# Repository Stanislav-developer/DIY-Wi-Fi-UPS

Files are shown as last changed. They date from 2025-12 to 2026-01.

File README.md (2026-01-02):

# DIY WiFi-UPS
## Джерело безперебійного живлення для WiFi роутерів та ONU терміналів

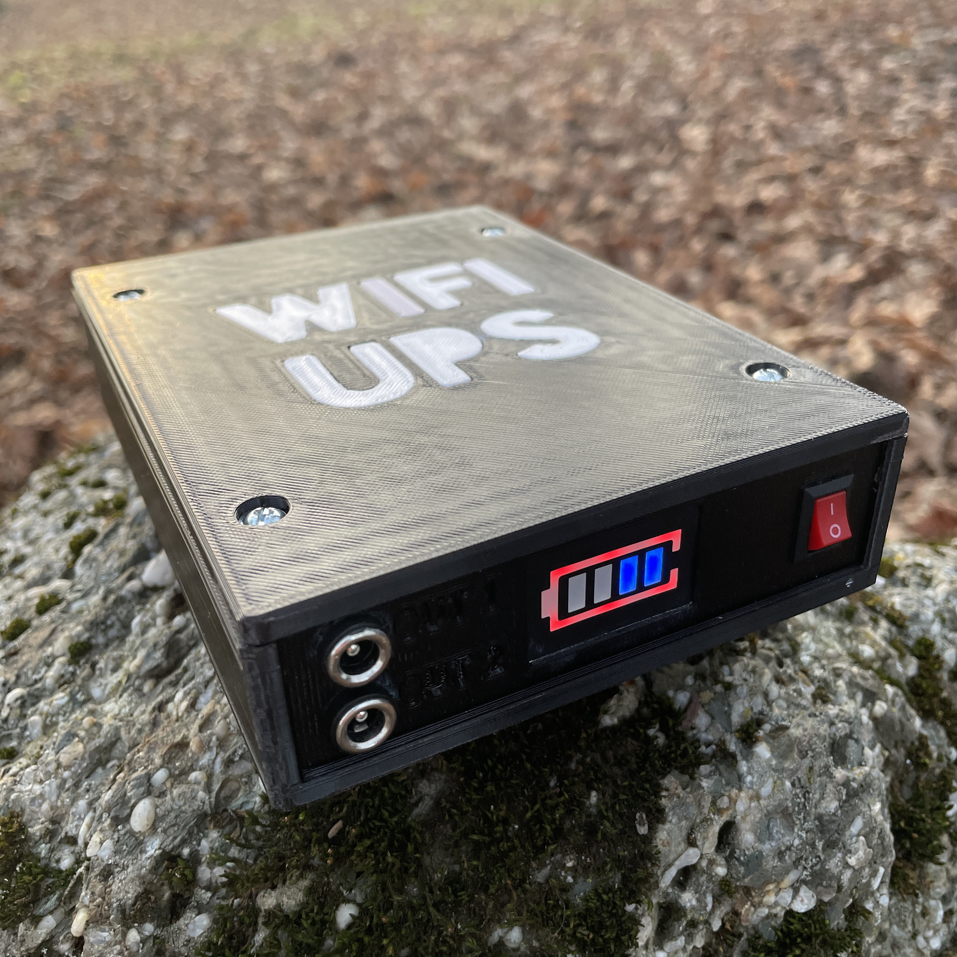
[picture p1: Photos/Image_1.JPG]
Main_Image


## 🎥 Відеоогляд


# Опис:
WiFi-UPS (ДБЖ для роутера) — це пристрій, який забезпечує безперебійне живлення для вашого Wi-Fi роутера та ONU-терміналу. Він складається з доступних компонентів і електронних модулів, що робить його простим для повторення. У цьому репозиторії описано будову та принцип роботи пристрою, наведено список необхідних компонентів і покрокову інструкцію зі збірки.

# Технічна інформація:
Особливістю цього безперебійника є безшовне перемикання на резервне живлення, тобто роутер не буде перезавантажуватися під час відключень електроенергії. Живлення безперебійника можливе як від блока живлення роутера (9–12 В, 600 мА–2 А), так і від стандартного блока живлення смартфона через USB Type-C (5 В, 1–3 А).
Пристрій має 2 входи та 2 виходи.
Характеристики вхідних портів:
• IN1 — розʼєм 5.5×2.1 мм, напруга від 6 до 20 В, струм до 3 А;
• IN2 — розʼєм USB Type-C, напруга 4.5–5.5 В, струм до 3 А.
Характеристики вихідних портів:
• OUT1, OUT2 — розʼєм 5.5×2.1 мм, напруга 9/12 В (за потреби може бути налаштована в діапазоні 5–25 В), струм до 1 А на порт.
Максимальна сумарна вихідна потужність на два порти становить 24 Вт.
Також на передній панелі розташовані індикатор заряду акумулятора та вимикач. Як елементи живлення використовуються 4 Li-Ion акумулятори формату 18650 з ємністю понад 1500 мА·год кожен.

# Характеристики у зручній таблиці:

| КАТЕГОРІЯ | ЗНАЧЕННЯ |
| :---: | :---: |
| Час автономної роботи | до 10 годин|
| Тип акумуляторів | Li-Ion 18650 |
| З'єднання елементів | 1s4p |
| Мін. ємність на комірку| 1500mAh |
| К-сть входів| 2 |
| К-сть виходів| 2 |
| Макс. потужність на 2 виходи| 24W |
| IN1 | 5-20 V (max 3A) |
| IN2 | 5V (max 3A) |
| OUT1 | 5/9/12V (max 1A) |
| OUT2 | 5/9/12V (max 1A) |

# Схема
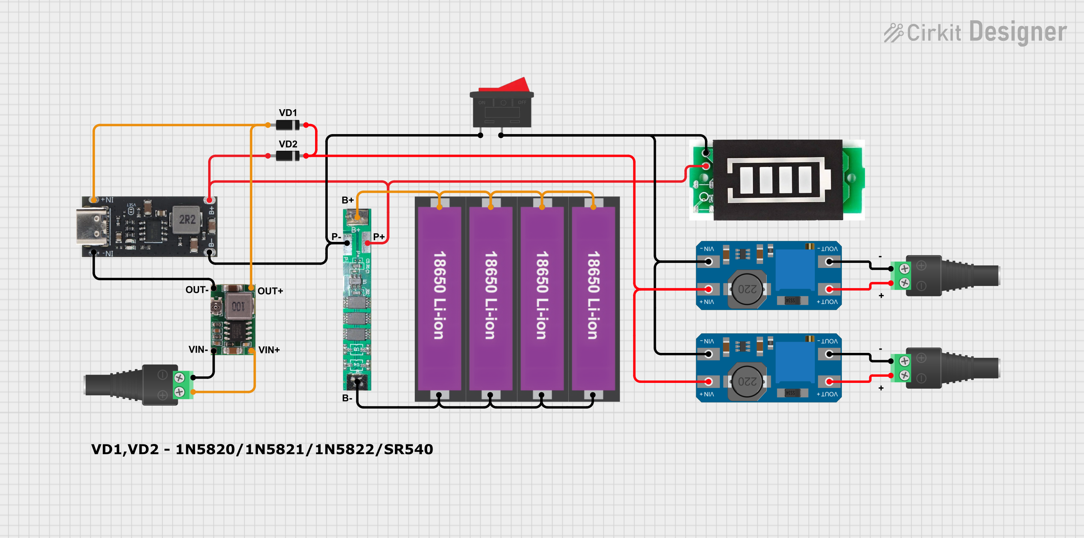
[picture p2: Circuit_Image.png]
Circuit_Image


[Переглянути схему у повній якості](/Circuit_Image.png)

# Принцип роботи
1. Акумулятори під'єднані до плати `BMS 1S 15A`, ця плата виконує функцію захисту від перерозряду та короткого замикання. Чому обрана саме ця бмс? Тому що струм на вході підвищуючих перетворювачів `MT3608` може сягати 6 Ампер і стандартна `BMS 1S` яка розрахована на 3A буде йти в захист.
2. До плати заряду `IP2312` підєднаний понижуючий dc-dc перетворювач `MINI360` призначений для конвертування напруги 9,12 вольт що поступає від блоку живлення роутеру у безпечні 5 вольт для плати заряду.
3. Функцію перемикання живлення від акумуляторів або від мережі виконують 2 діоди шотткі `SR540`. VD1 пропускає напругу 5 вольт якщо присутня мережа, оскільки на цьому діоді більший потенціал то VD2 закритий і напруга з акумуляторів не поступає до підвищуючих перетворювачів та плата заряду безпечно їх заряджає. Якщо електроенергія у мережі зникає, потенціал на VD1 дорівнює 0 і VD2 відкривається та живлення на перетворювачі поступає від акумуляторів. Таким чином виходить система: Присутня мережа - живимо роутер та термінал від мережі та паралельно заряджаємо акумулятори. Мережа зникла - моментально перемикаємося на живлення від акумуляторів(роутер не перезавантажується).
4. Коли ми вмикаємо вимикач, струм паралельно поступає на 2 dc-dc підвищуючі модулі `MT3608` та на `індикатор заряду` акумулятора. Таким чином ми вмикаємо безперебійник.
   
# Корпус

Корпус моделювався у програмі `Fusion360`, у папці [3D models](/3D%20Models/) розміщений файл проекту [f3z](/3D%20Models/V1.1%20(Latest)/Fusion%20file) та [STL](/3D%20Models/V1.1%20(Latest)/STLs) файли для друку. Файли рекомендовано використовувати з папки [V1.1(Latest)](/3D%20Models/V1.1%20(Latest)/) оскільки це остання версія де виправлені деякі дрібні недоліки.

---

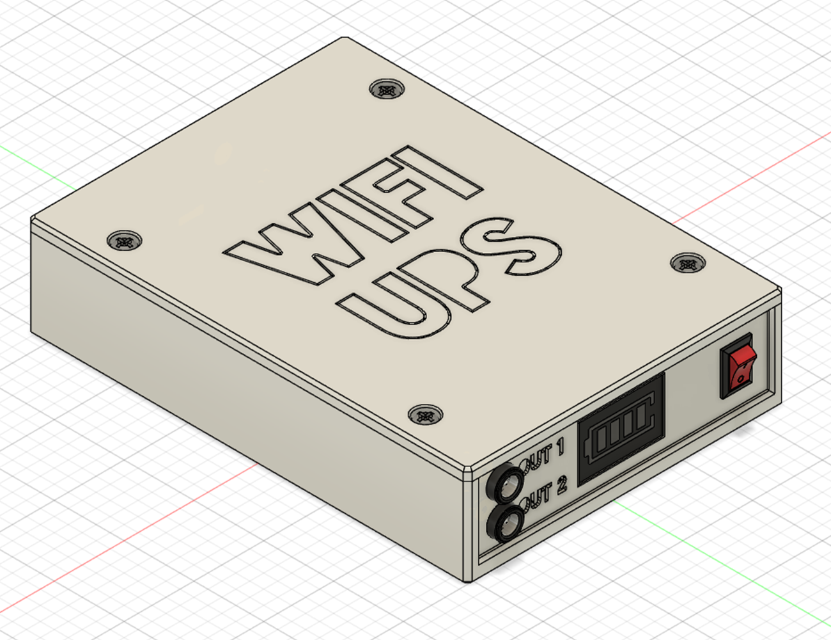
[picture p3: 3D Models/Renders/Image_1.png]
Circuit_Image

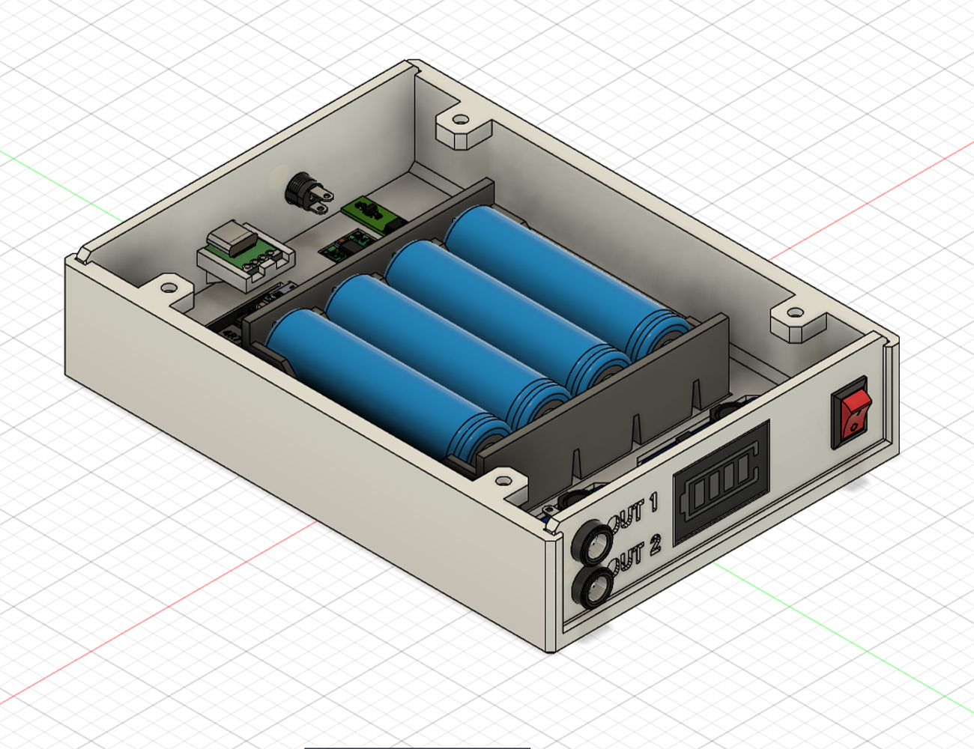
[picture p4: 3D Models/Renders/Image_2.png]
Circuit_Image

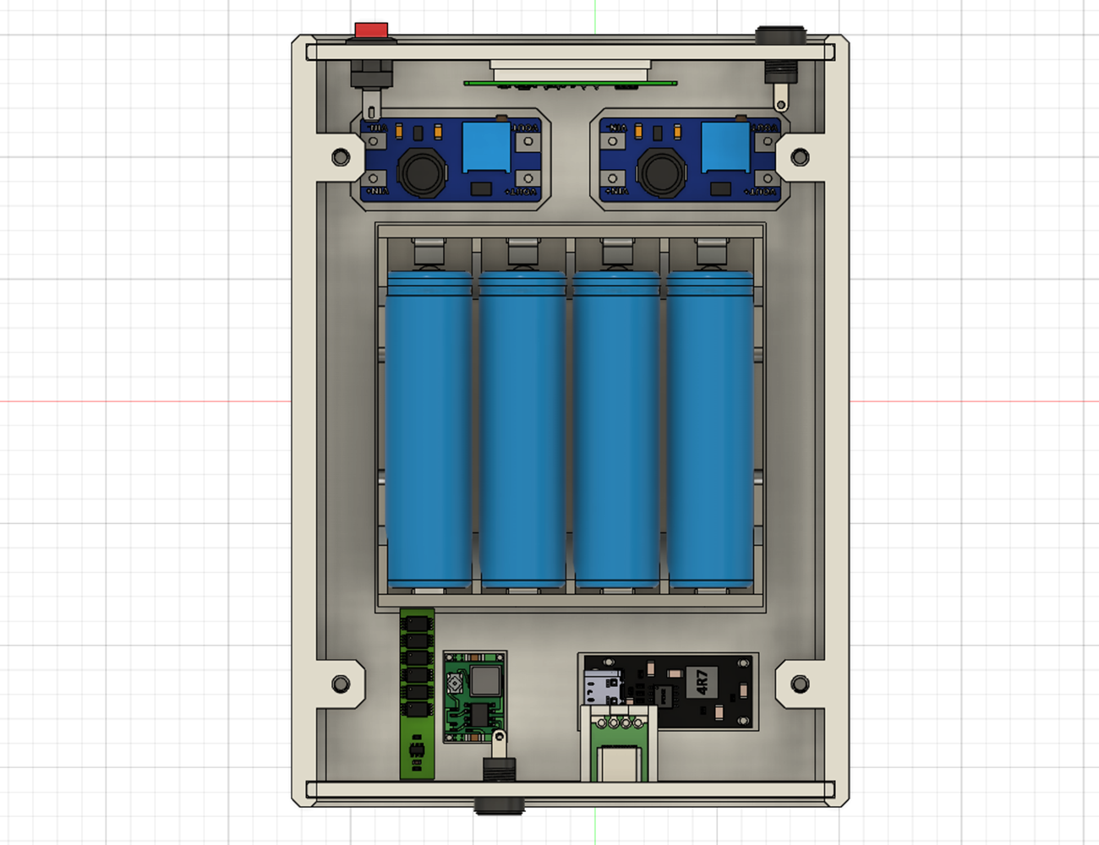
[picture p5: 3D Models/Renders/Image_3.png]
Circuit_Image

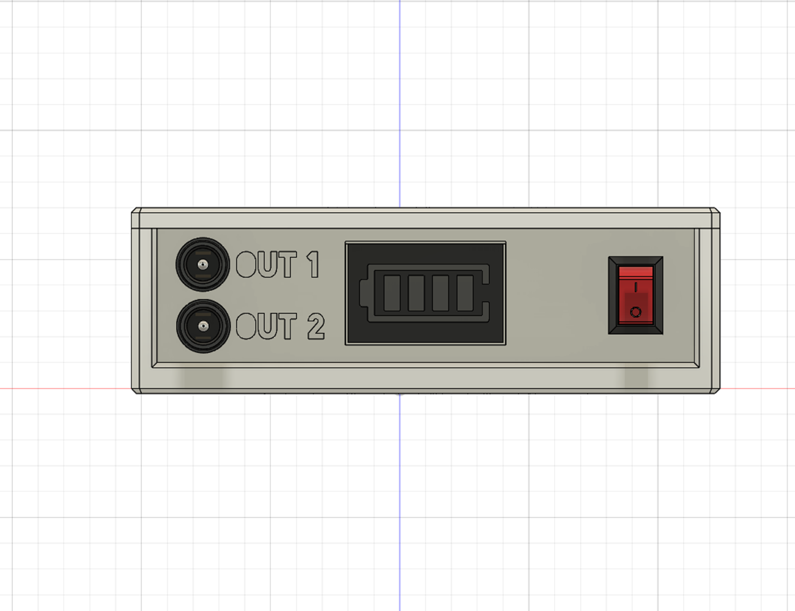
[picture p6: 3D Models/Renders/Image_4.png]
Circuit_Image

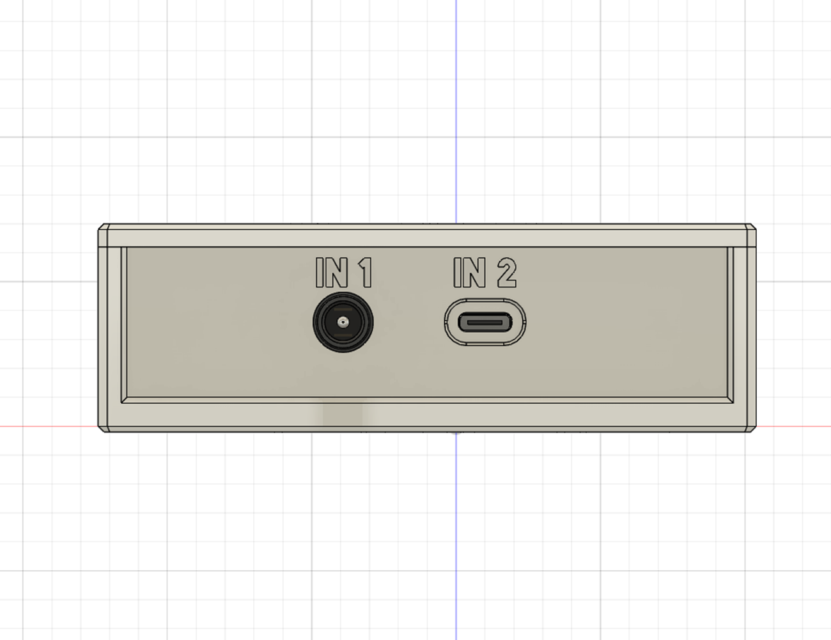
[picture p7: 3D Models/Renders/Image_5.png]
Circuit_Image

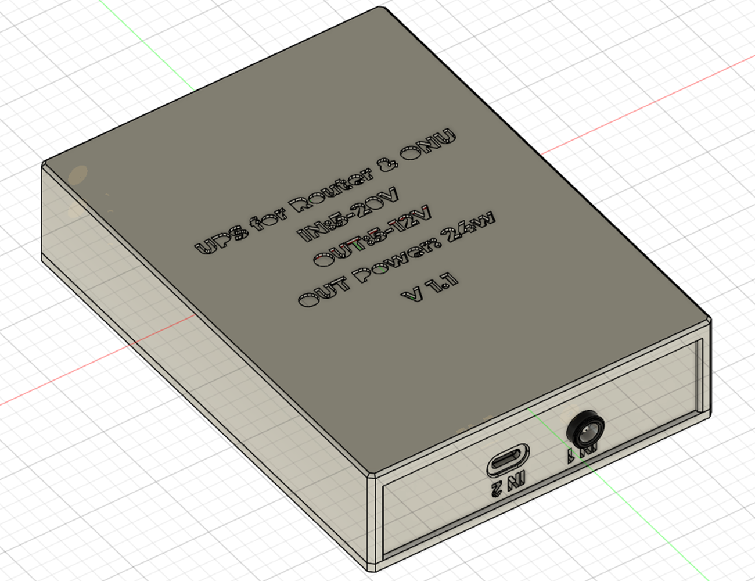
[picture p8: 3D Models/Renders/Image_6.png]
Circuit_Image

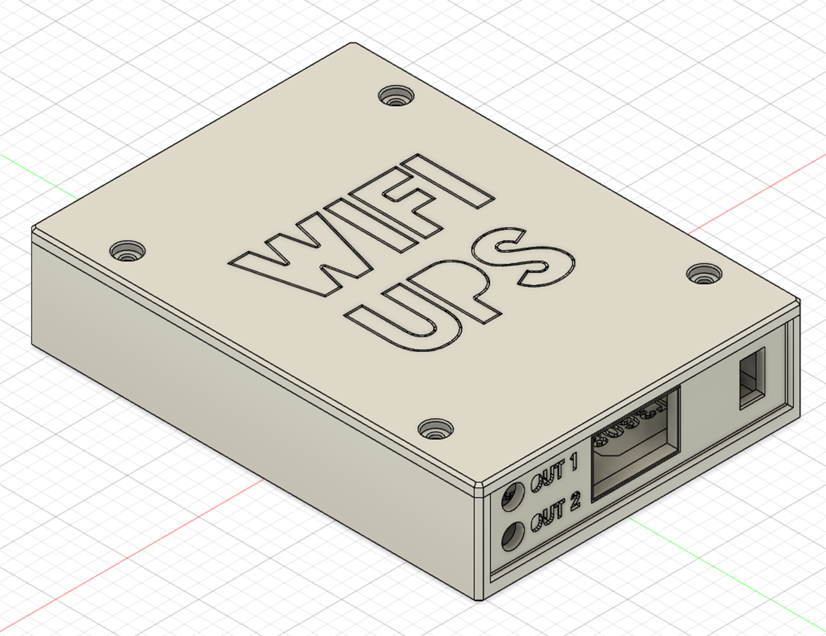
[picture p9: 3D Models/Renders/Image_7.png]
Circuit_Image

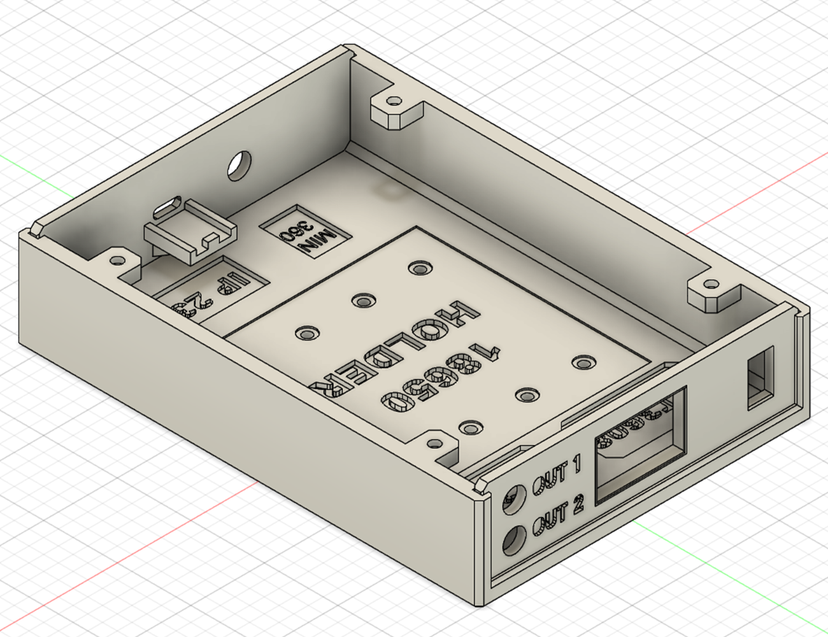
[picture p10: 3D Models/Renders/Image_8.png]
Circuit_Image


Корпус проектувався модульно та складається з 5 частин:
1. Основний кейс
2. Передня панель
3. Задня панель
4. Кришка
5. Букви

Складання корпусу:
У основному кейсі є 4 отвори під гайки М3 та спеціальні пази з двох сторін у які вставляється передня та задня панелі, верхня кришка їх прижимає і закручується болтами M3x6 до основного кейсу, на верхню кришку ми наносимо суперклей у отвори під букви та закладаємо їх.

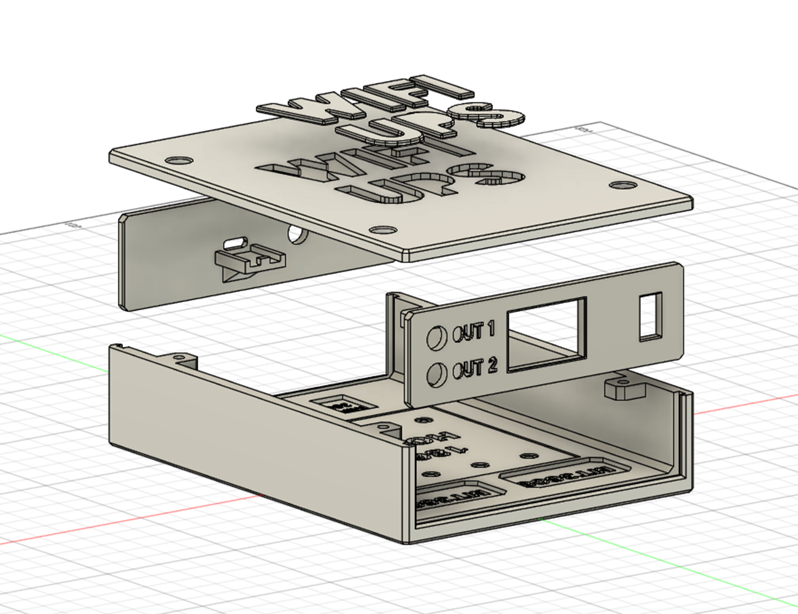
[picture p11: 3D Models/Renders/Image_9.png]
Circuit_Image

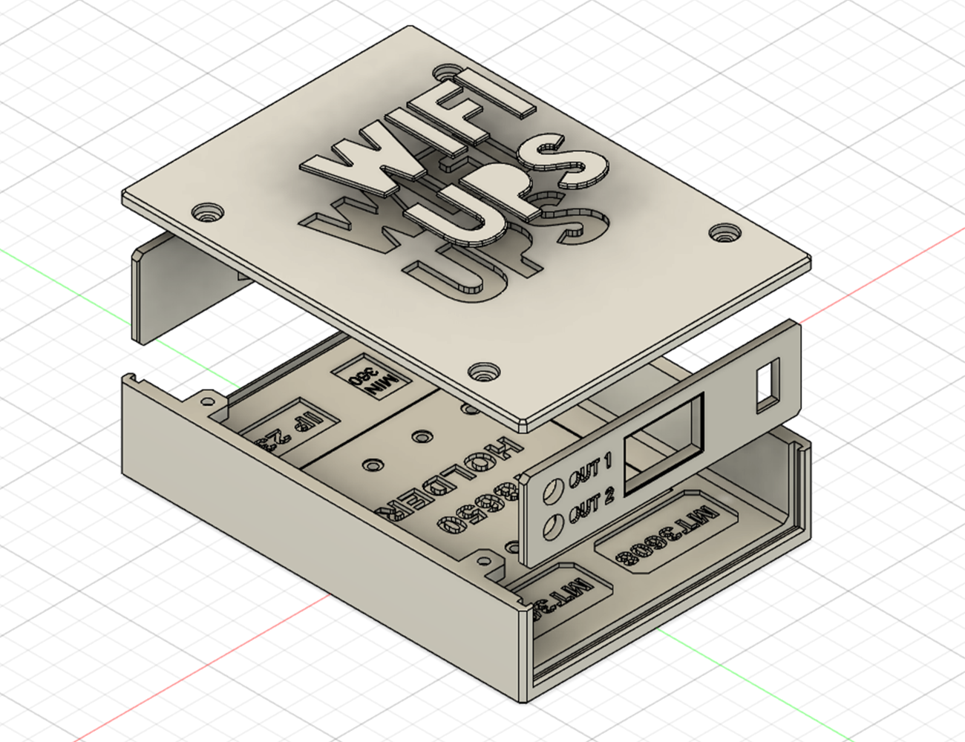
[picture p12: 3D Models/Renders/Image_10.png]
Circuit_Image


## [Файл Fusion f3z для редагування](/3D%20Models/V1.1%20(Latest)/Fusion%20file)
## [STL файли для друку](/3D%20Models/V1.1%20(Latest)/STLs)

# Необхідні компоненти для збірки

| НОМЕР | НАЗВА | КІЛЬКІСТЬ |
| :---: | :---: | :--: |
| 1 | [Холдер для 4-х акумуляторів 18650](https://www.rcscomponents.kiev.ua/product/korpus-dlia-4x18650-gt-18650-pc8_179556.html) | 1шт |
| 2 | [Підвищуючий dc-dc перетворювач MT3608](https://www.rcscomponents.kiev.ua/product/rehulovanyi-dc-dc-step-up-modul-zhyvlennia-mt3608_123033.html) | 2шт |
| 3 | [Плата заряду IP2312](https://www.rcscomponents.kiev.ua/product/modul-zariadnyi-type-c-dlia-18650-1s-3a-4-2v_188209.html) | 1шт |
| 4 | [Понижувальний dc-dc модуль MINI360](https://www.rcscomponents.kiev.ua/product/dc-dc-ponyzhuiuchyi-peretvoriuvach-z-rehuliuvanniam-mini-360-vkhid-4-75v-23v-vykhid-1-0v-17v-2a_200045.html) | 1шт |
| 5 | [Плата BMS 1S 15A](https://myproject.com.ua/bms-6mos-modul-zakhystu-dlia-li-ion-akumuliatora-1s.html) | 1шт |
| 6 | [Індикатор заряду для 1s Li-Ion](https://www.rcscomponents.kiev.ua/product/indykator-zariadu-litiievoi-batarei-1s-synii_211004.html) | 1шт |
| 7 | [DC гніздо 5.5x2.1mm](https://www.rcscomponents.kiev.ua/product/hnizdo-zhyvlennia-chorne-na-korpus-5-5x2-1mm-dc-022b_213085.html) | 3шт |
| 8 | [DC штекер 5.5x2.1mm](https://www.rcscomponents.kiev.ua/product/shteker-na-kabel-2-1-5-5-korotkyi-pc-2-1-5-5-vylka-zhyvlennia-dc-mama-z-korpusom-2-1-5-5-mm-dovzhyna-9mm_25189.html) | 4шт |
| 9 | [Вимикач KCD-11](https://www.rcscomponents.kiev.ua/product/kcd-11-on-off-spst-2p-vymykaie-0-vmykaie-peremykach-klavishnyi-rocker-global-tone_211814.html) | 1шт |
| 10 | [TypeC плата адаптер](https://myproject.com.ua/usb31-type-c-plata-perekhidnyk.html) | 1шт |
| 11 | [Діоди Шотткі 1N5820/SR540](https://www.rcscomponents.kiev.ua/product/sr540_20328.html) | 2шт |
| 12 | [Макетна плата (необов'язково)](https://www.rcscomponents.kiev.ua/product/maketna-plata-2x8-dvostoronnia-zelena_144385.html) | 1шт |
| 13 | [Силіконовий термостійкий кабель 20AWG](https://www.rcscomponents.kiev.ua/product/sylikonovyi-provid-20awg-0-5mm-100-0-08ts-korychnevyi_210526.html) | 3м |
| 14 | [Болти M3x6](https://www.rcscomponents.kiev.ua/product/hvynt-iz-sferychnoiu-holovkoiu-m3x6-nerzhaviiucha-stal-304-ph-din-7985_194111.html) | 12шт |
| 15 | [Гайки М3](https://www.rcscomponents.kiev.ua/product/haika-m3-otsynk-bila-din934-b3-bn117_26436.html) | 4шт |
| 16 | Акумулятори 18650 ємністю > 1500mAh | 4шт |
| 17 | Роздрукований корпус | 1шт |

# Всі деталі в зборі

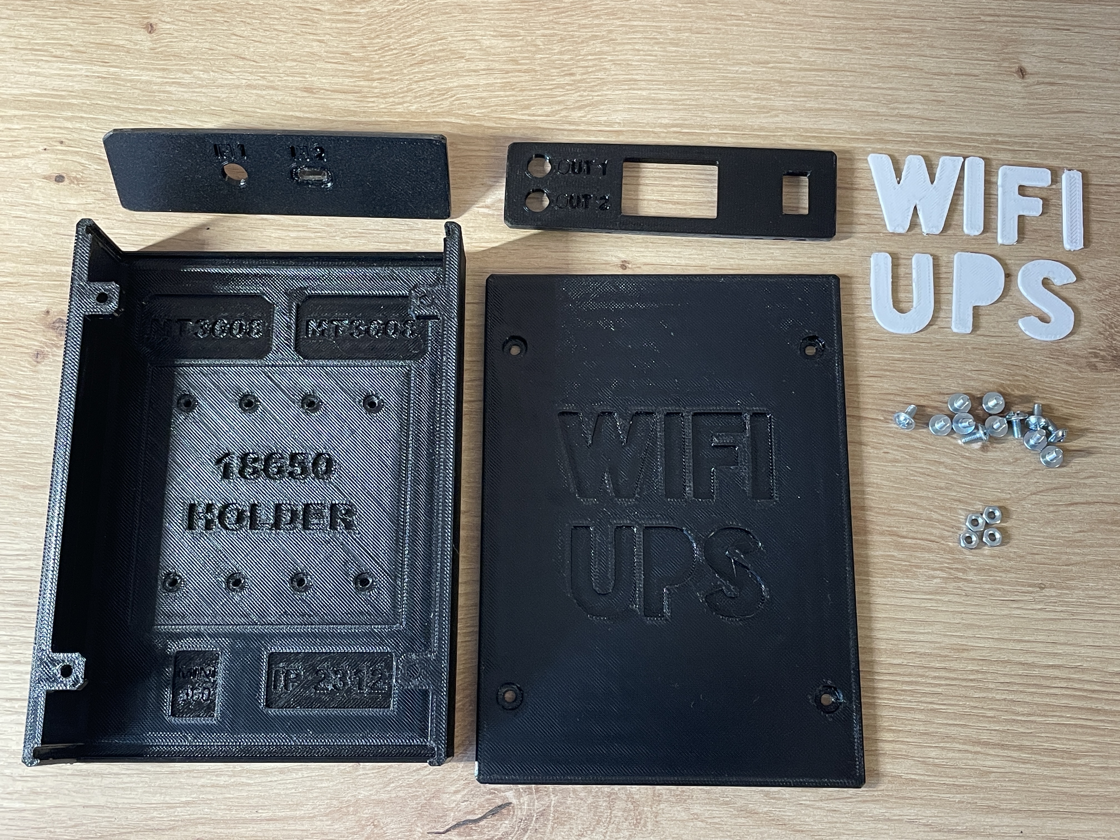
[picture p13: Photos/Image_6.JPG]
Circuit_Image

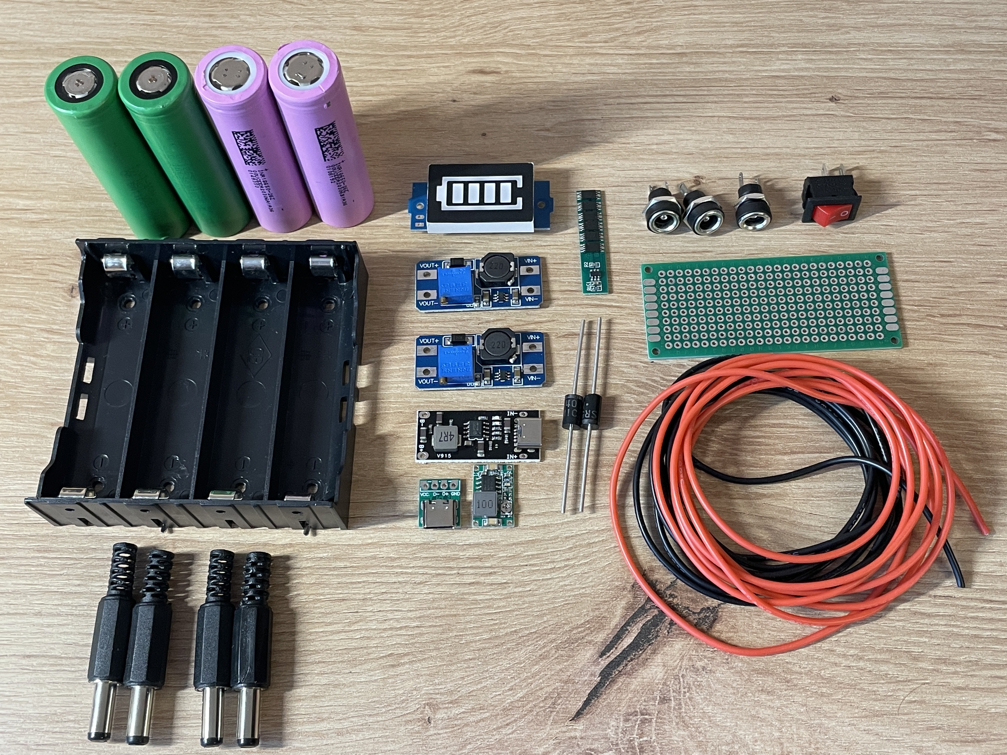
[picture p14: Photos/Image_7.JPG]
Circuit_Image


# Процес збірки
### 1. Припаюємо всі комірки холдера паралельно.
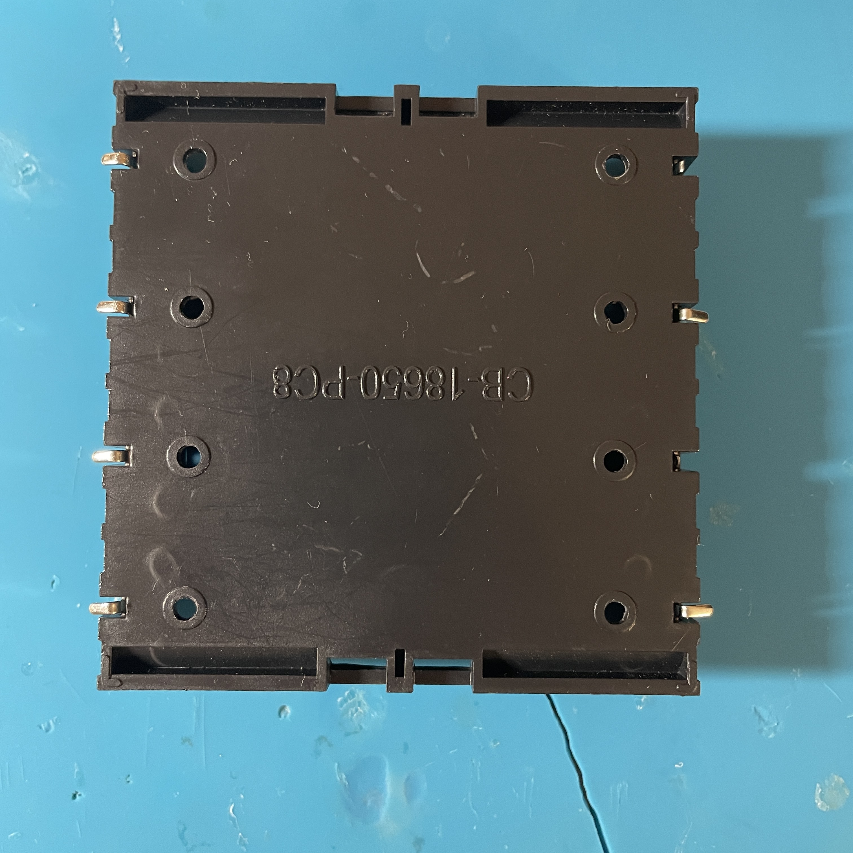
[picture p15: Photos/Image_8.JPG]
Circuit_Image

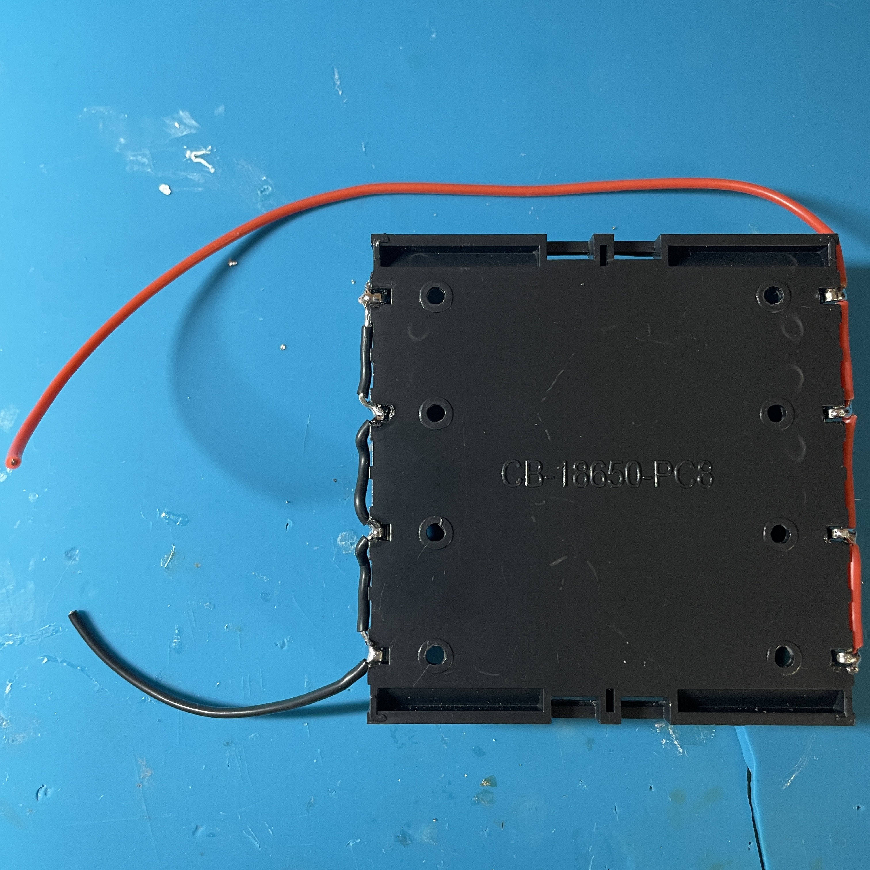
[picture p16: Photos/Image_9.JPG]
Circuit_Image


### 2. Припаюємо плату `BMS 3S 15A`.
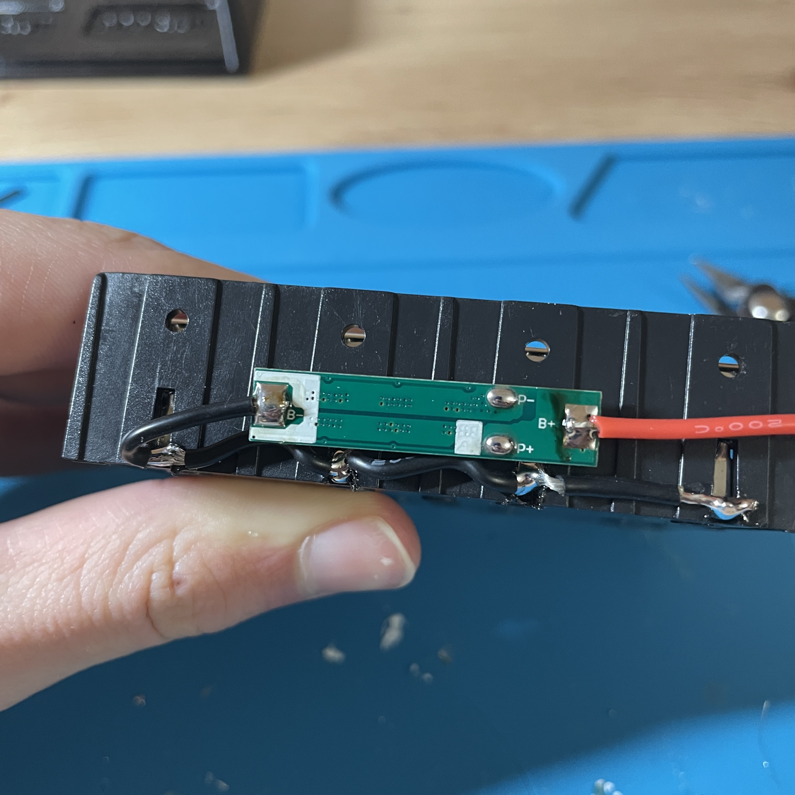
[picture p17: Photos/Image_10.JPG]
Circuit_Image


### 3. Надалі використовуватиметься температурно стійкий клей герметик `Kafuter 704`.
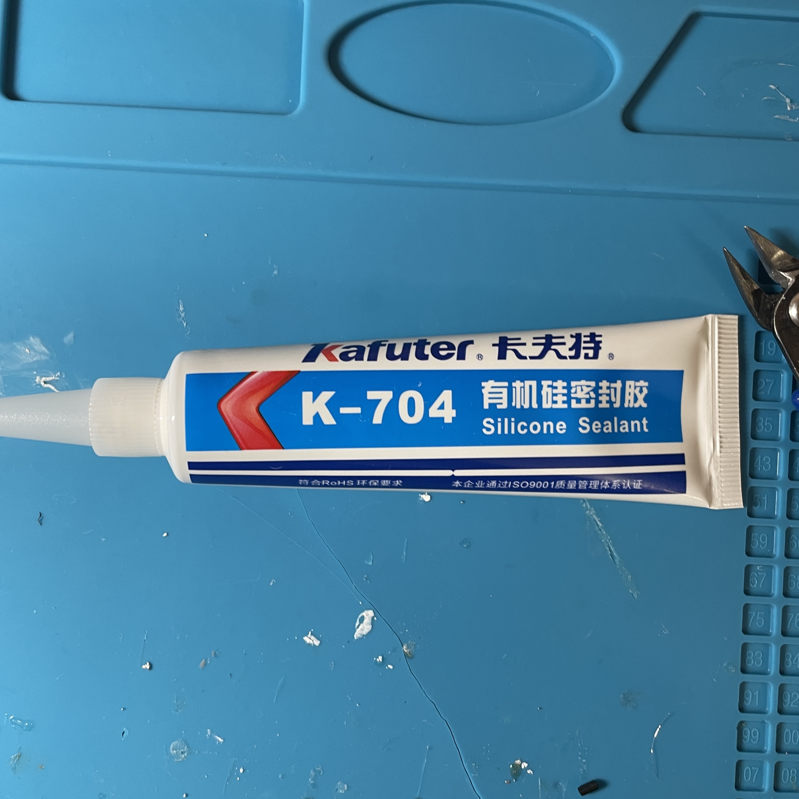
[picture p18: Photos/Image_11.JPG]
Circuit_Image


### 4. Кріпимо плату BMS герметиком на холдер.
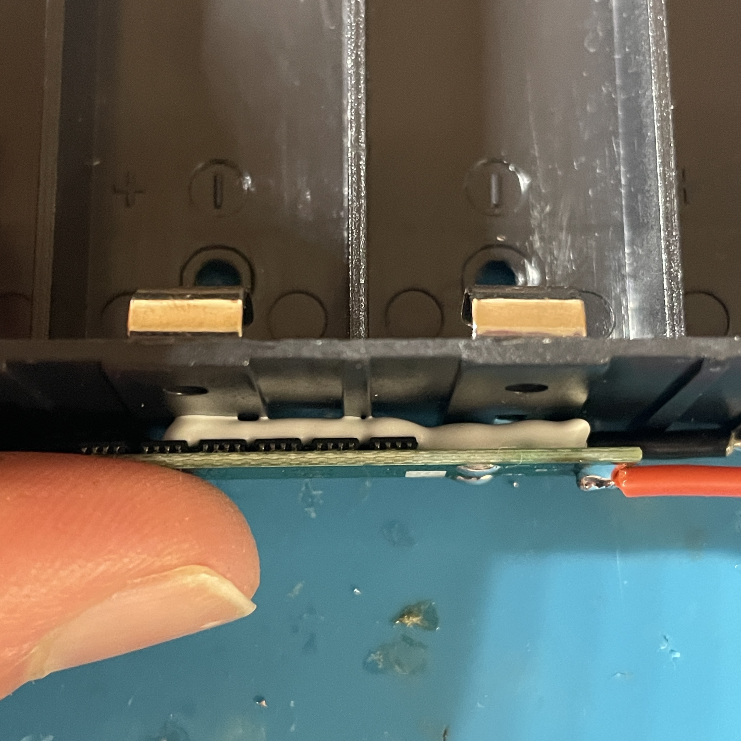
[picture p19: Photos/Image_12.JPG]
Circuit_Image


### 5. Закручуємо холдер болтами у корпус.
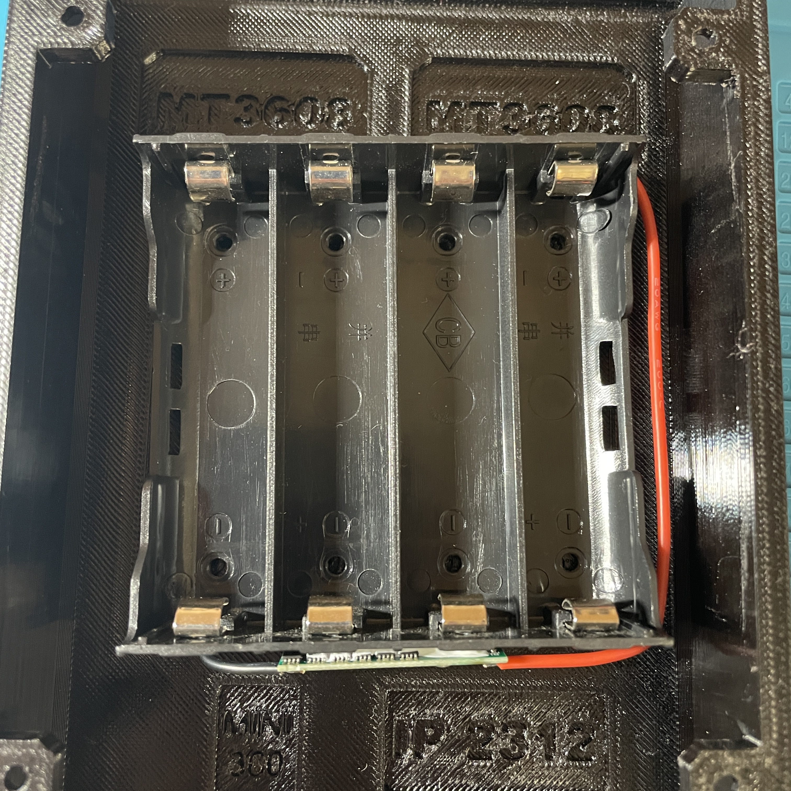
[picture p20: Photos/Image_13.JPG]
Circuit_Image

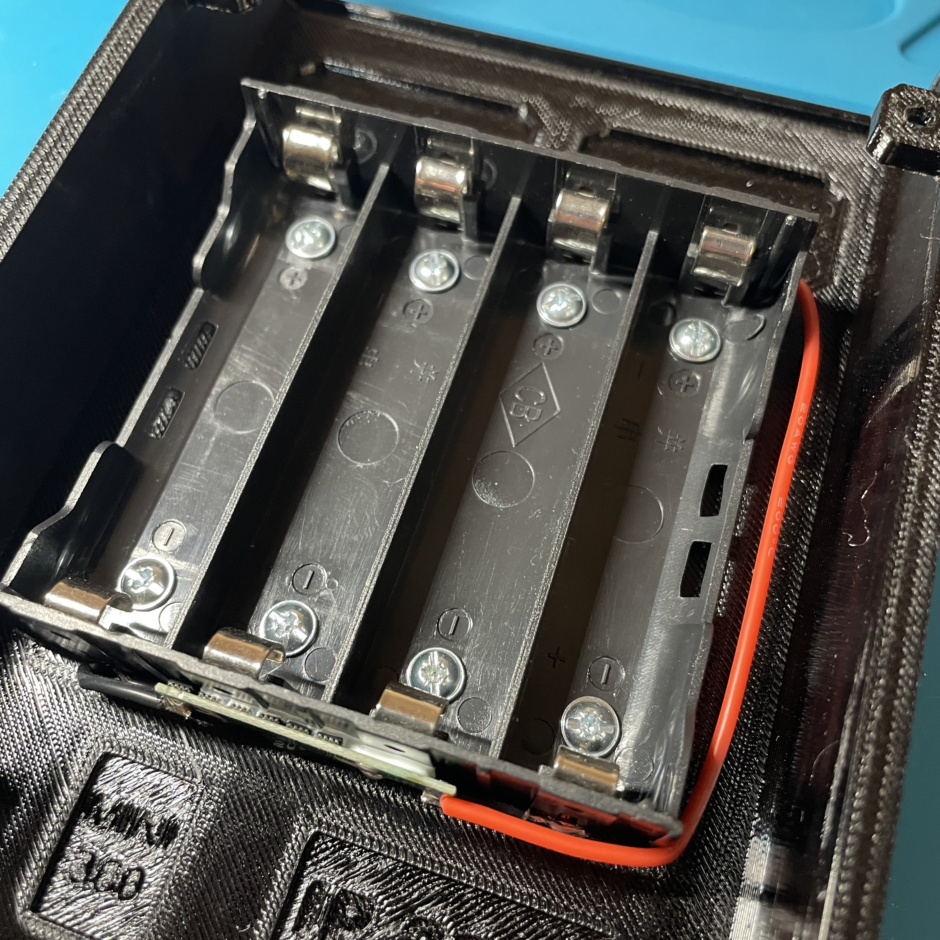
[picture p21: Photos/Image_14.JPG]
Circuit_Image


### 6. Налаштовуємо необхідну напругу на модулях `MT3608` та `MINI360`.
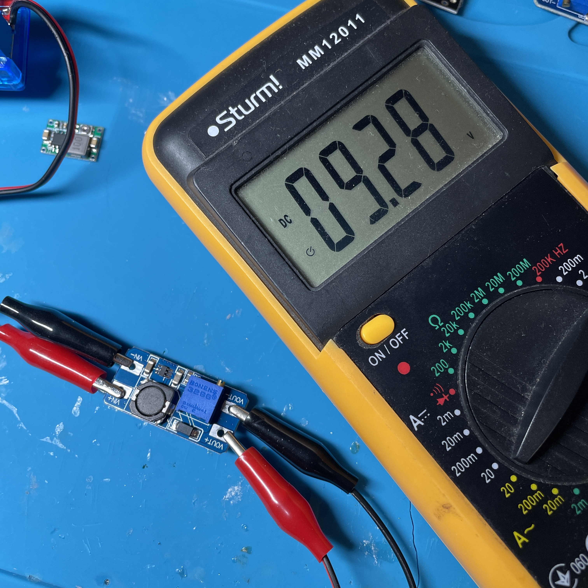
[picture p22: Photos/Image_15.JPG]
Circuit_Image

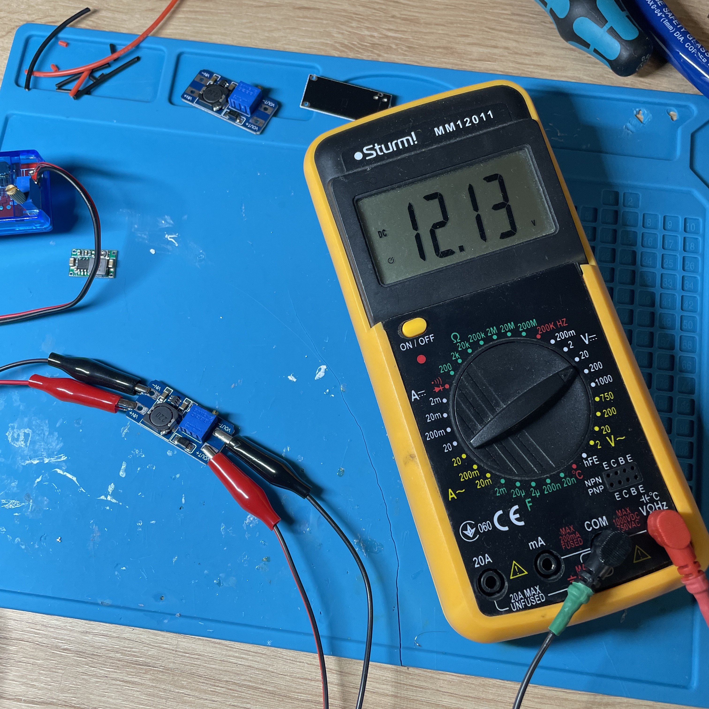
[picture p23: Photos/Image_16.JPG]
Circuit_Image

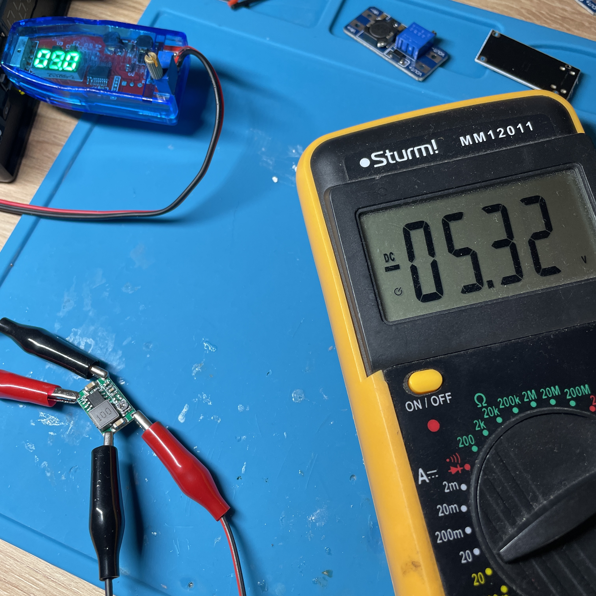
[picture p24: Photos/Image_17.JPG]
Circuit_Image


### 7. Лудимо контакти на модулях.
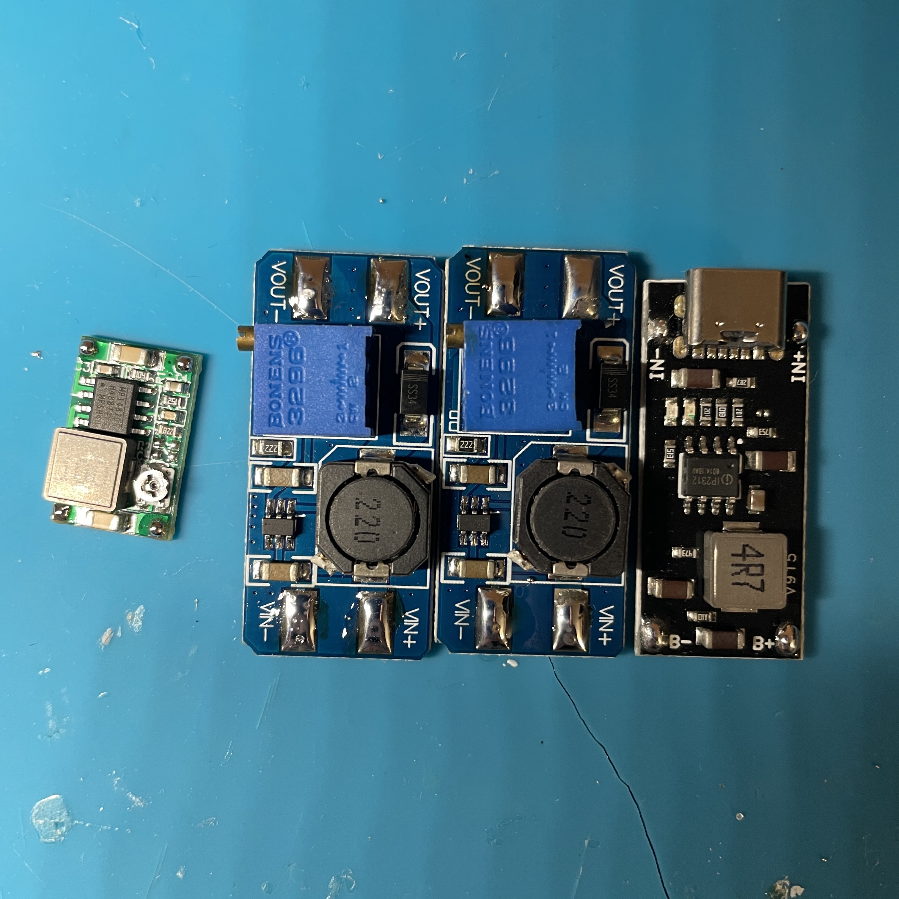
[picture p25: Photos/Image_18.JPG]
Circuit_Image


### 8. Наносимо клей герметик на посадкові місця.
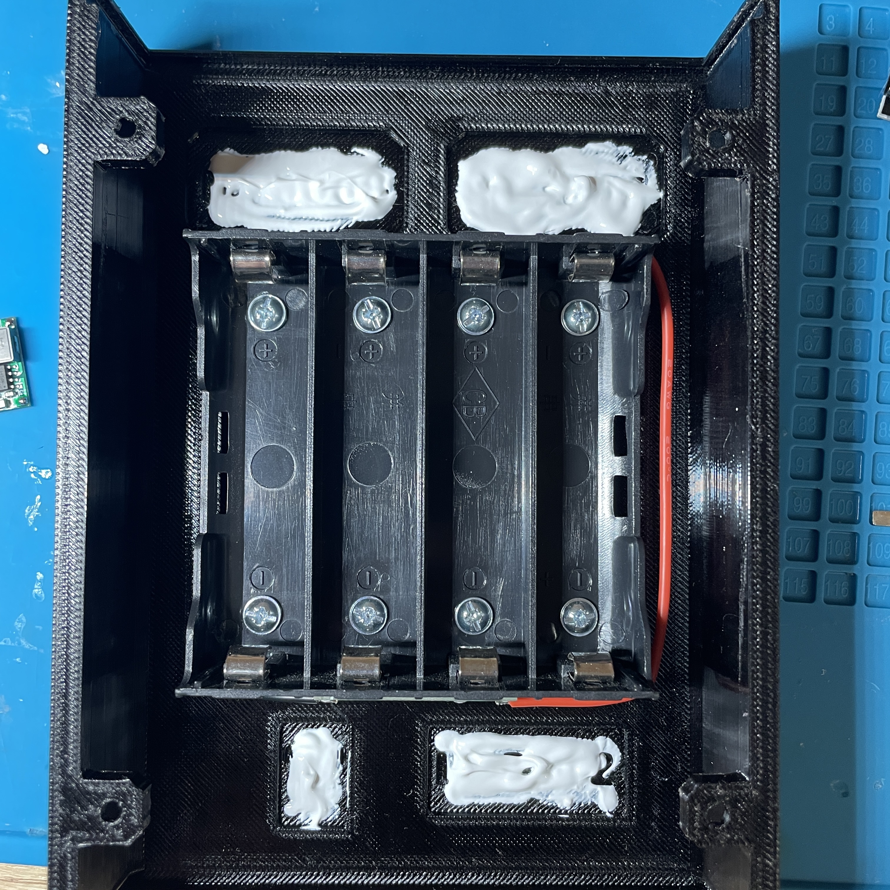
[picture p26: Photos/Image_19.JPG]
Circuit_Image


### 9. Садимо модулі на посадкові місця.
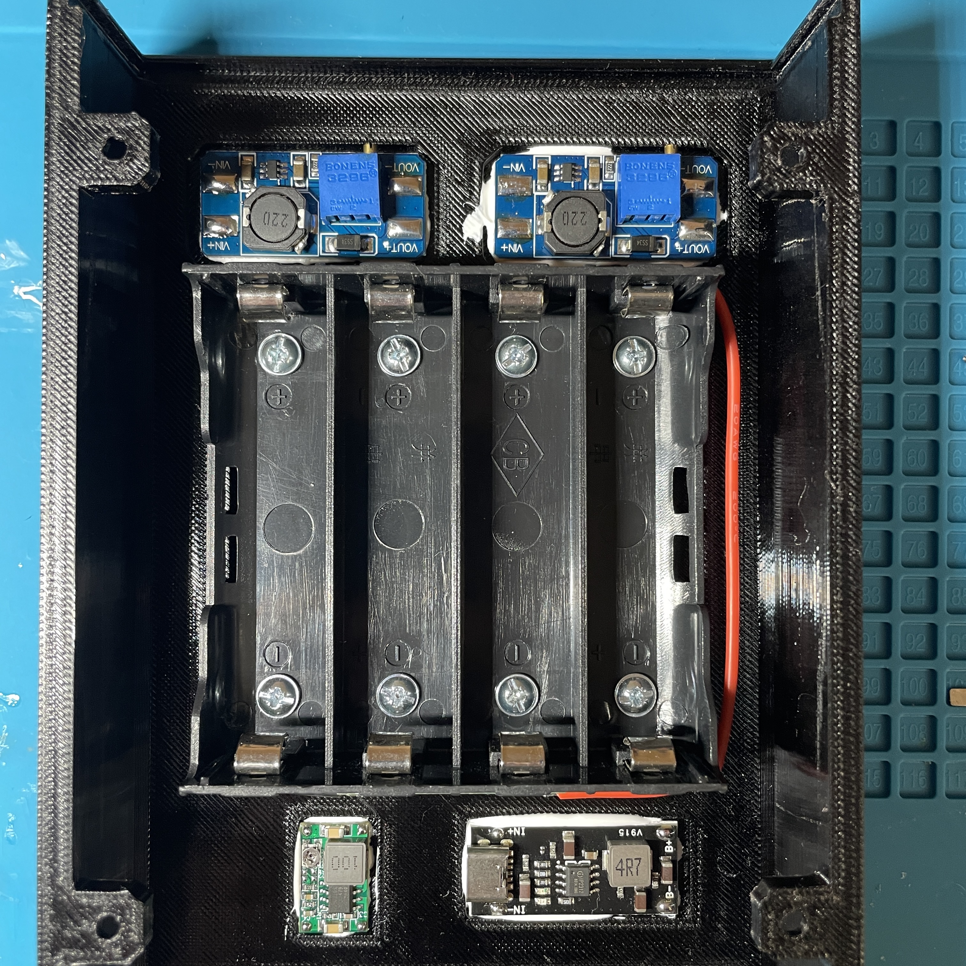
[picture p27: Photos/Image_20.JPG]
Circuit_Image


### 10. Лудимо контакти та вставляємо `плату адаптер з type-c роз'ємом` у паз.
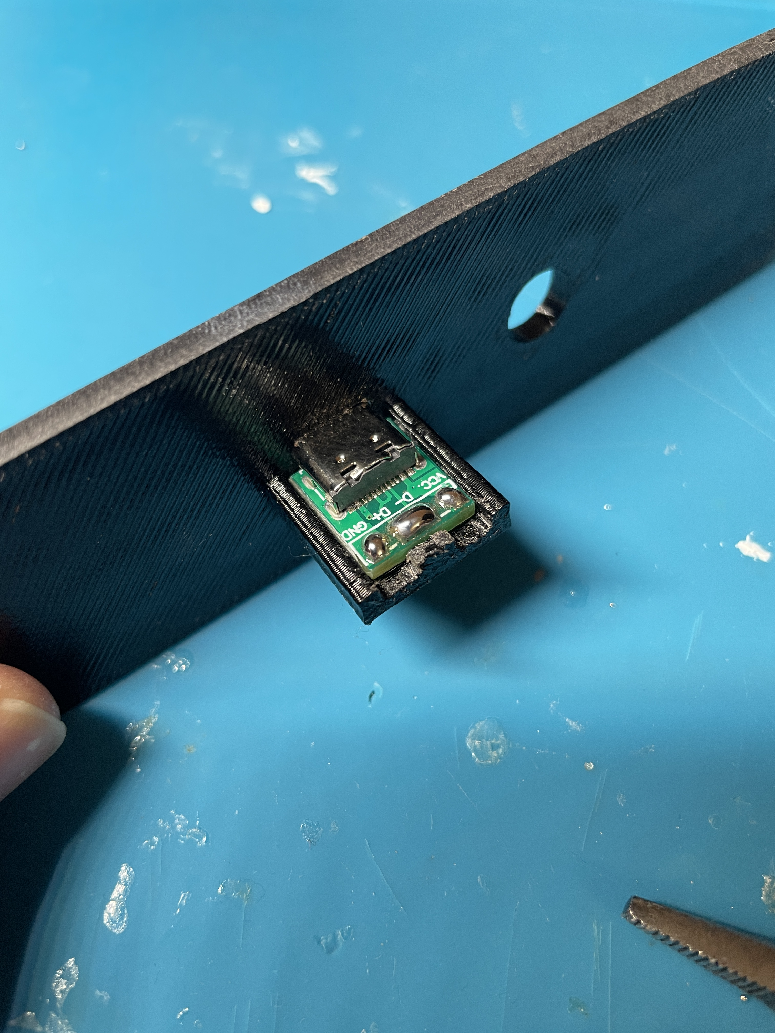
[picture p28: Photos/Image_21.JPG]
Circuit_Image


### 11. Припаюємо кабелі до DC гнізд та ізолюємо термоусадками.
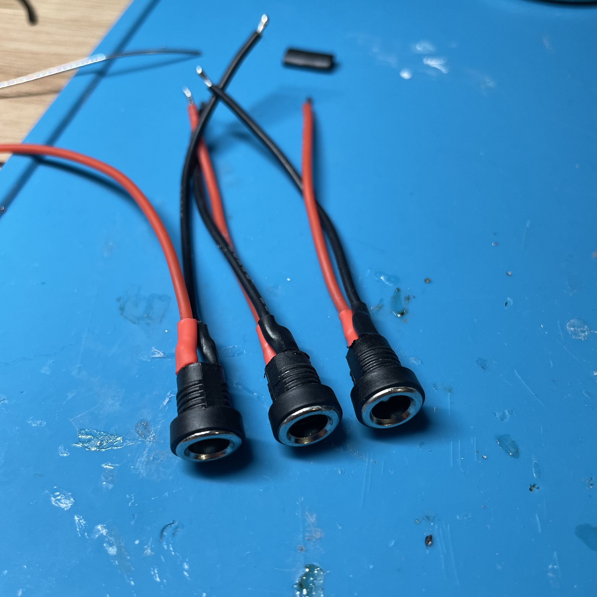
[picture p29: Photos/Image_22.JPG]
Circuit_Image


### 12. Закріплюємо гнізда на передній та задній панелі.
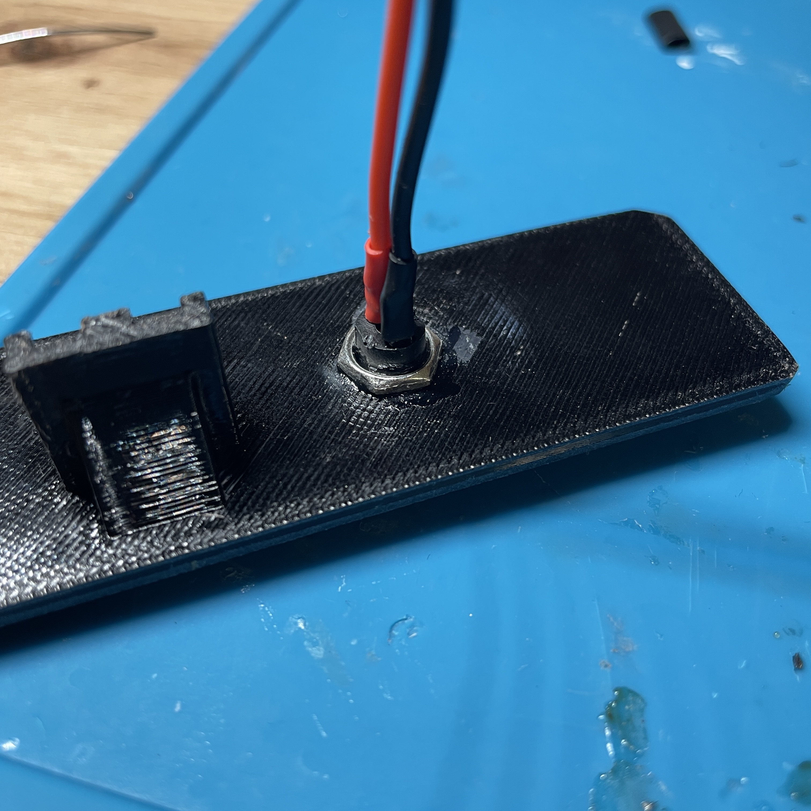
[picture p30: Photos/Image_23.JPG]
Circuit_Image

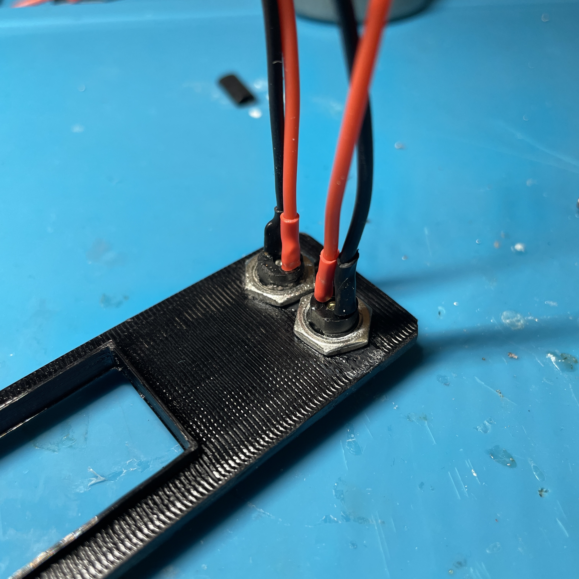
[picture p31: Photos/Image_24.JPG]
Circuit_Image


### 13. Припаюємо кабелі до `індикатора заряду` та вставляємо його у паз на передній панелі.
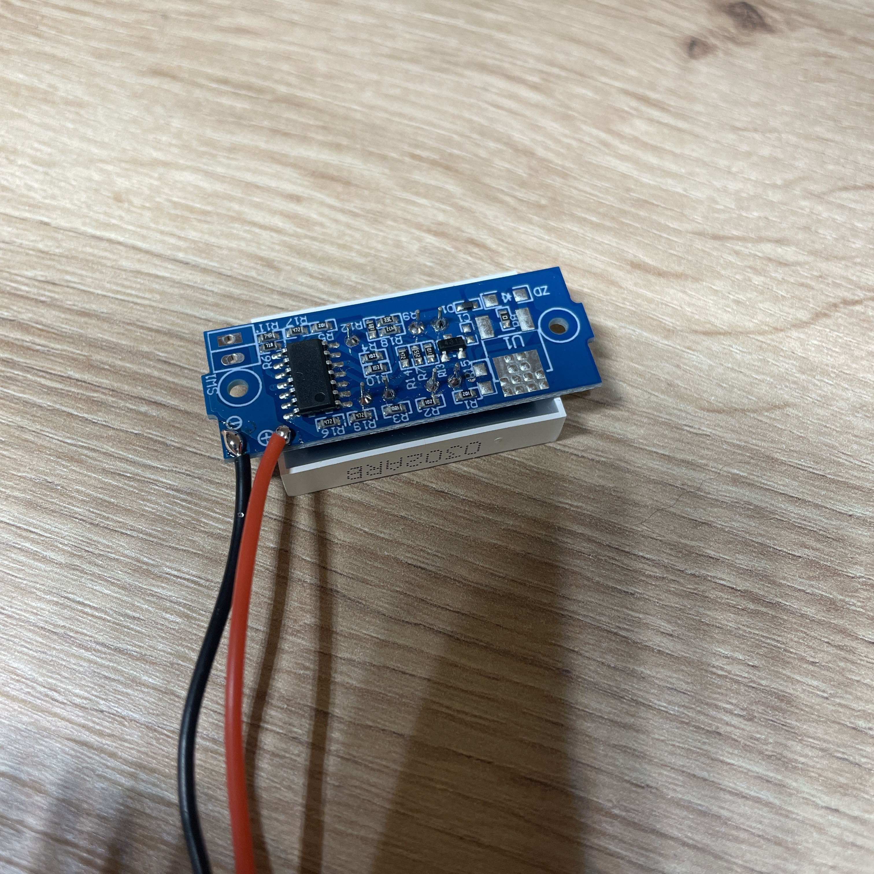
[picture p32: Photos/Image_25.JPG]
Circuit_Image

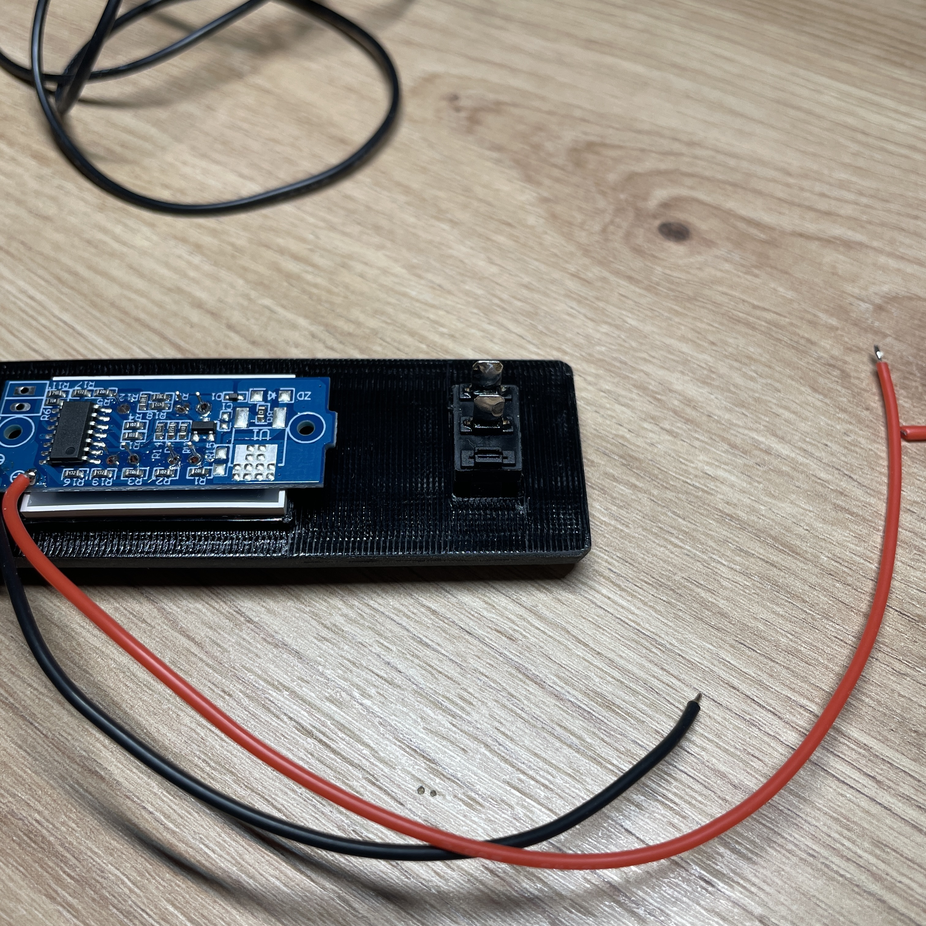
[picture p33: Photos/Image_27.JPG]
Circuit_Image

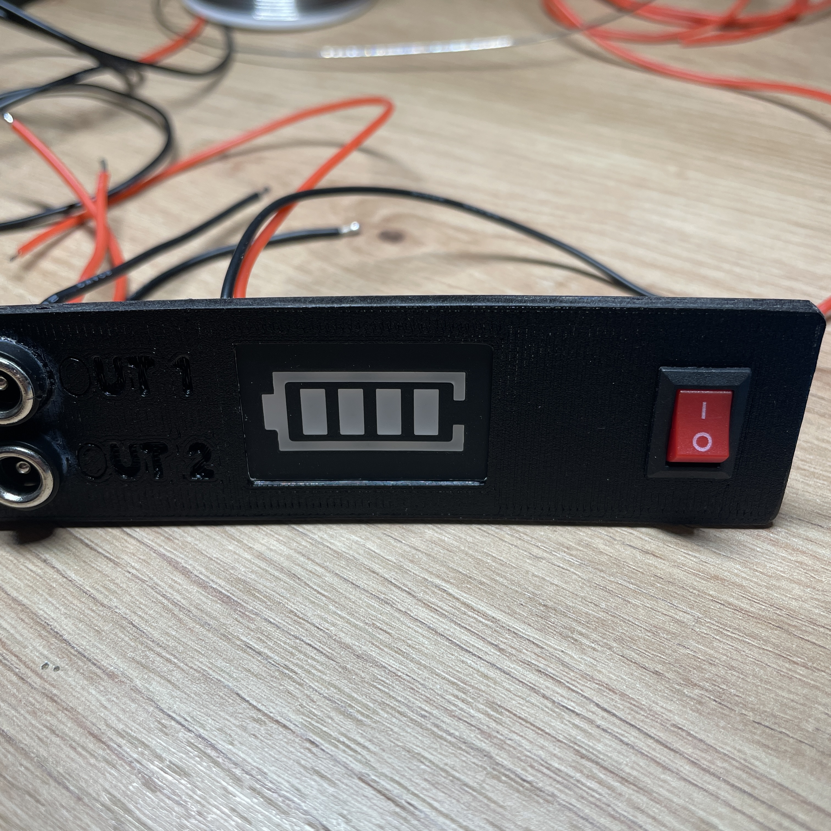
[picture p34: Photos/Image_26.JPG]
Circuit_Image


### 14. Запаюємо 2 діоди на макетну плату.
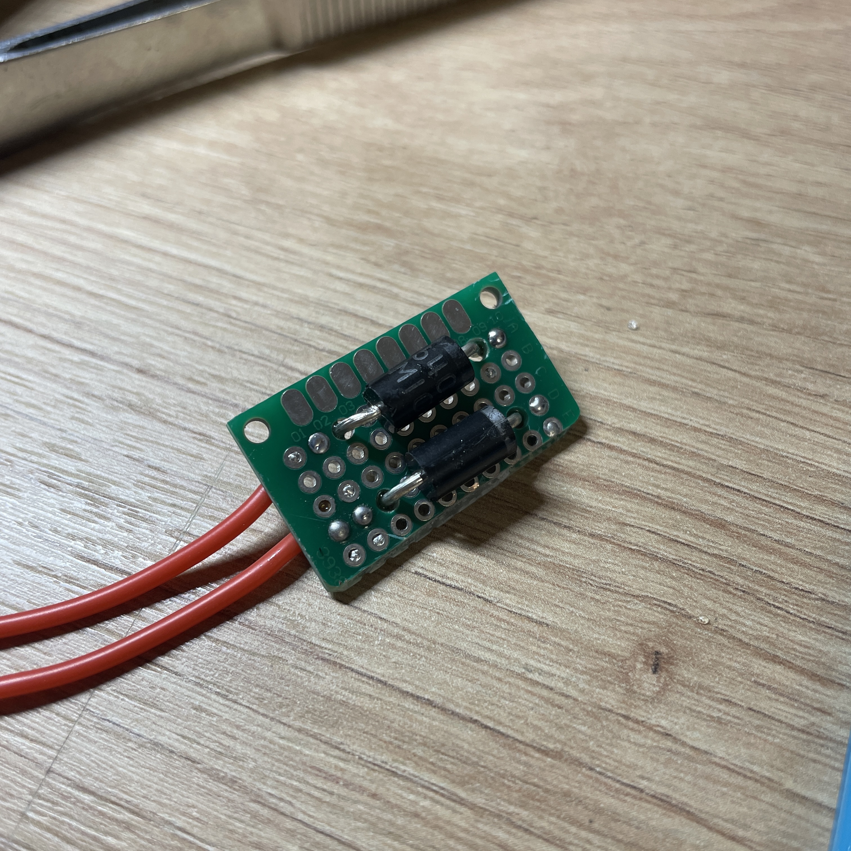
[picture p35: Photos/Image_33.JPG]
Circuit_Image

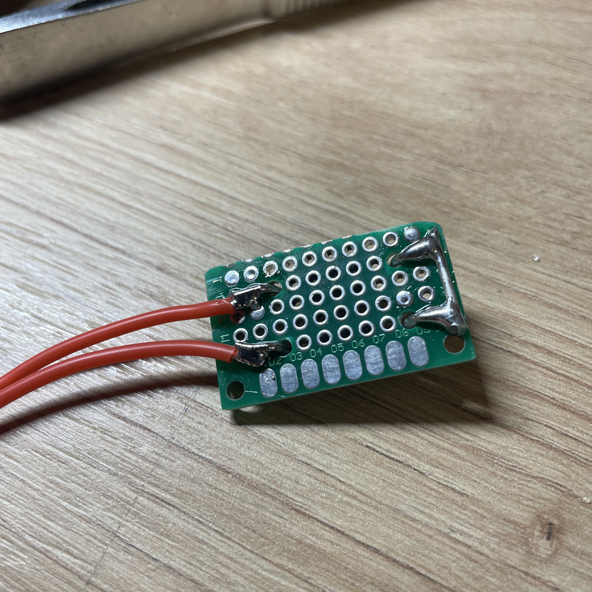
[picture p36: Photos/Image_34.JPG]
Circuit_Image


### 15. Далі паяємо всі провідники по схемі.
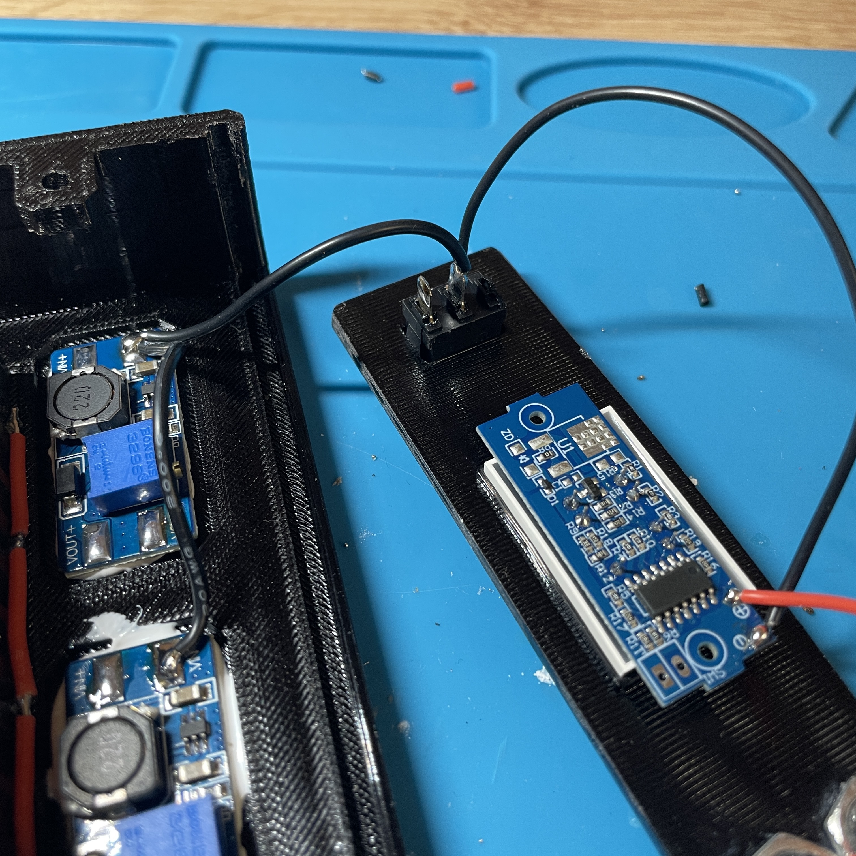
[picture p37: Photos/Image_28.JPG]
Circuit_Image

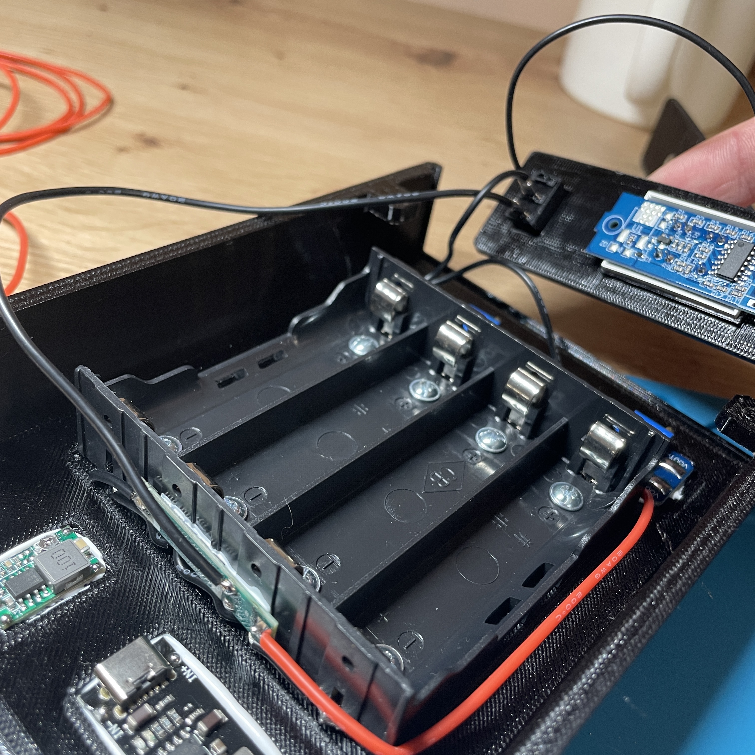
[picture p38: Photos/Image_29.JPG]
Circuit_Image

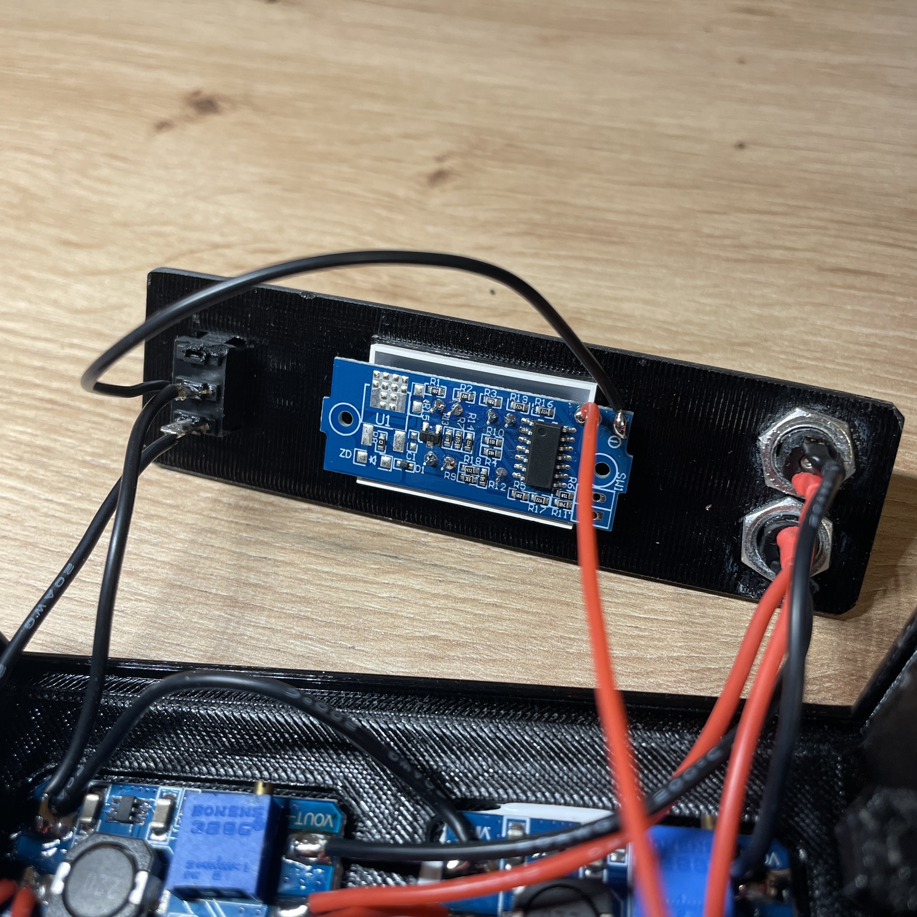
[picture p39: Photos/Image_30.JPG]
Circuit_Image

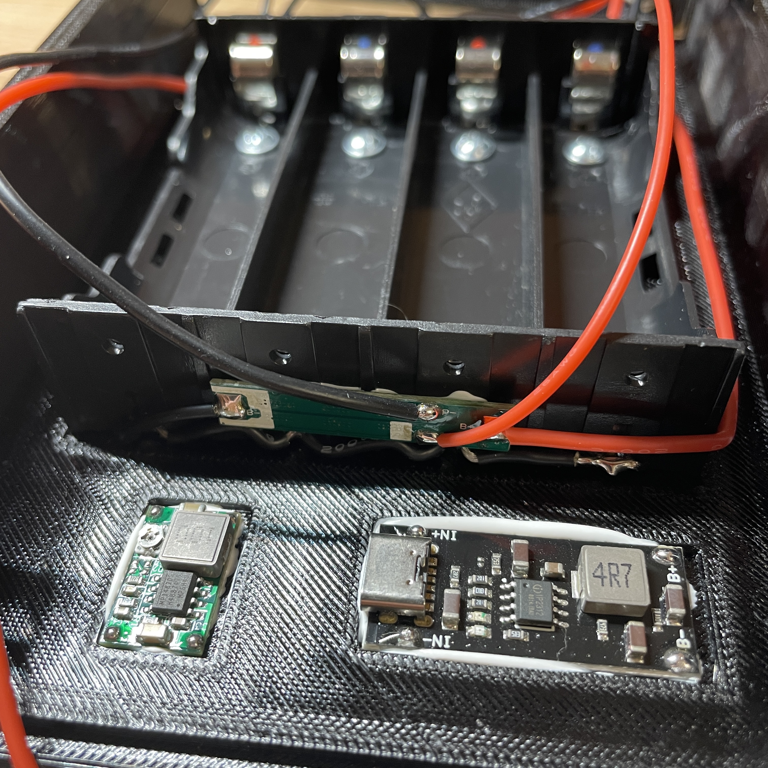
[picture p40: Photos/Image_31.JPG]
Circuit_Image

Circuit_Image
Circuit_Image
Circuit_Image
Circuit_Image

Circuit_Image

### 16. Ще раз перевіряємо схему на правильність підключення та правильною полярністю вставляємо акумулятори у холдер.
Circuit_Image
Circuit_Image

### 17. На верхню кришку по середині клеємо якийсь ущільнювач з паралону чи гуми, щоб акумулятори не випадали з холдеру.
Circuit_Image

### 18. Закладаємо гайки у пази, закладаємо верхню кришку, закручуємо болтами та вклеюємо надруковані букви. 
Circuit_Image

### 19. Далі зробимо 2 DC-DC кабеля для роутера та ONU терміналу
Circuit_Image

### 20. Припаюємо + та - до штекерів
Circuit_Image

### 21. Закручуємо пластикові кожухи.
Circuit_Image

# Фінальний результат:
Circuit_Image
Circuit_Image
Circuit_Image
Circuit_Image
Circuit_Image

# 💬 Зворотний зв'язок

Буду вдячний за підтримку цього проєкту! Відкритий до критики, запитань, порад і пропозицій.

**Зв'яжіться зі мною:**



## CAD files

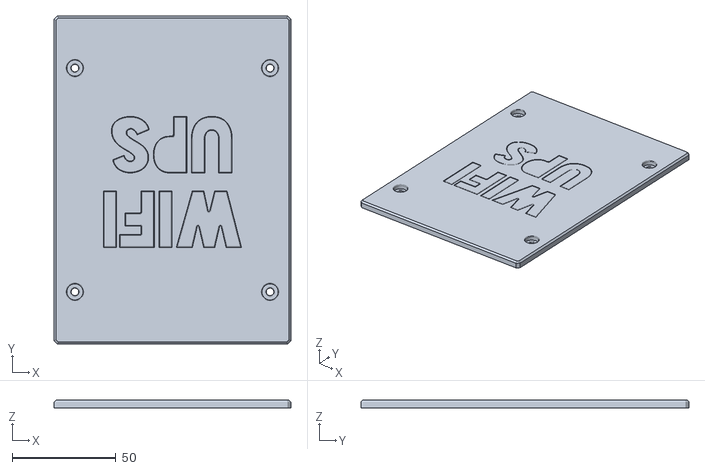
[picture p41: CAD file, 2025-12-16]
3D Models/V1.0/STLs/Cover.stl
114.0 x 158.0 x 4.00

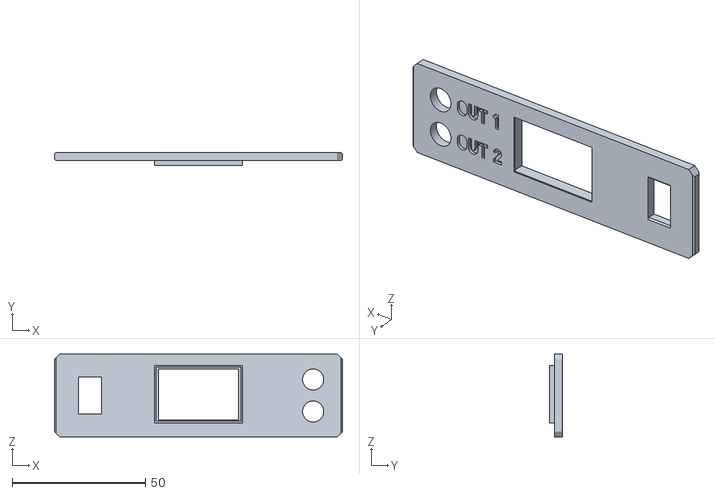
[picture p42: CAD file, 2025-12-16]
3D Models/V1.1 (Latest)/STLs/Front_Panel.stl
108.0 x 5.00 x 31.0

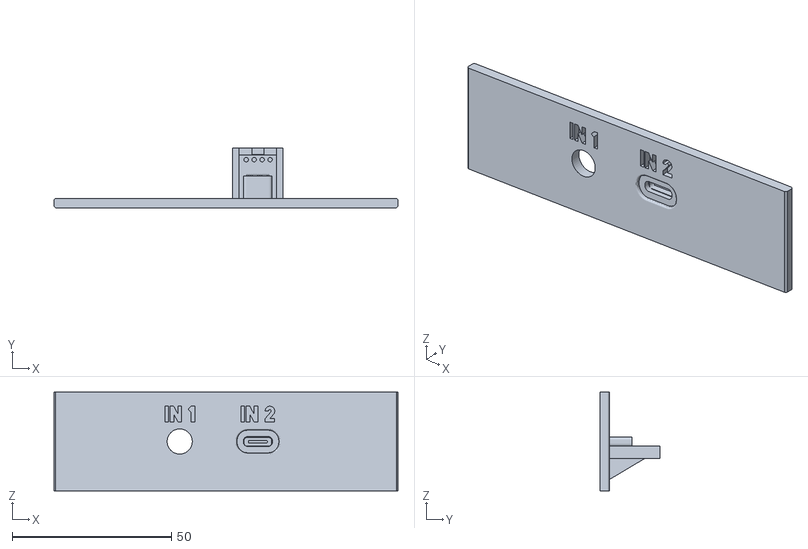
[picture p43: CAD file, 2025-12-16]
3D Models/V1.0/STLs/Back_Panel.stl
108.0 x 18.8 x 31.0

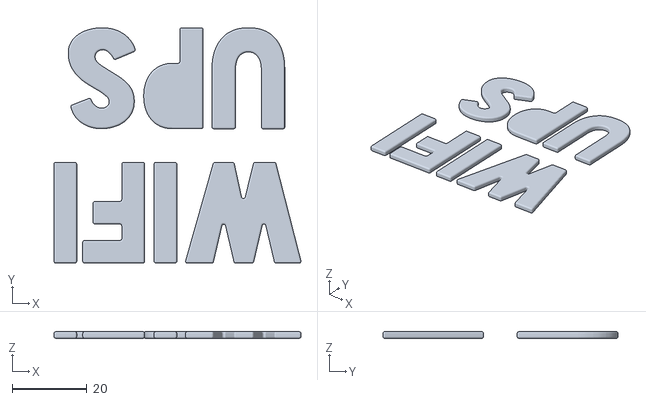
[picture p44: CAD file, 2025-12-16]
3D Models/V1.0/STLs/Text.stl
66.1 x 63.0 x 1.80

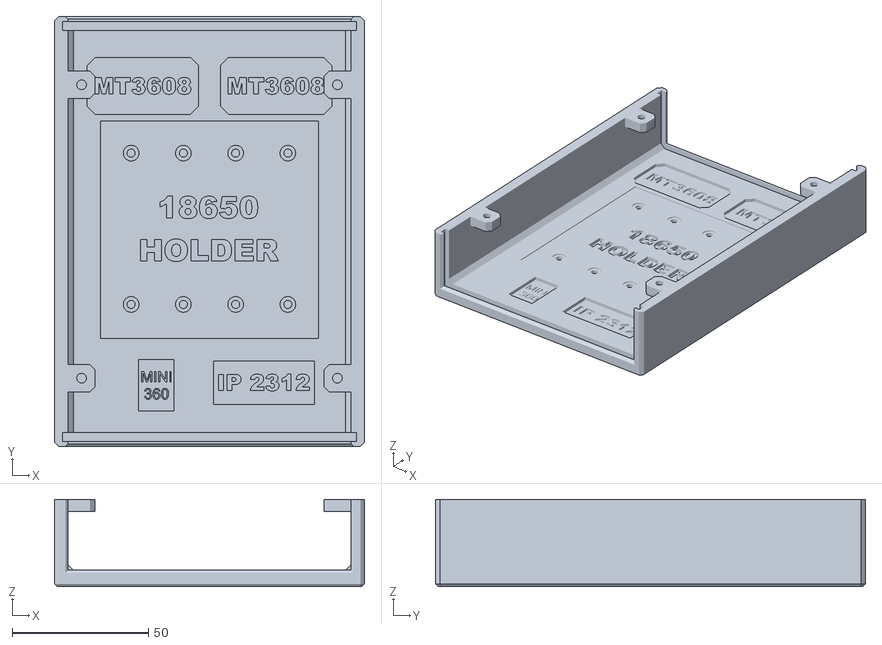
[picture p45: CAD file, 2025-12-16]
3D Models/V1.0/STLs/Case.stl
114.0 x 158.0 x 32.0

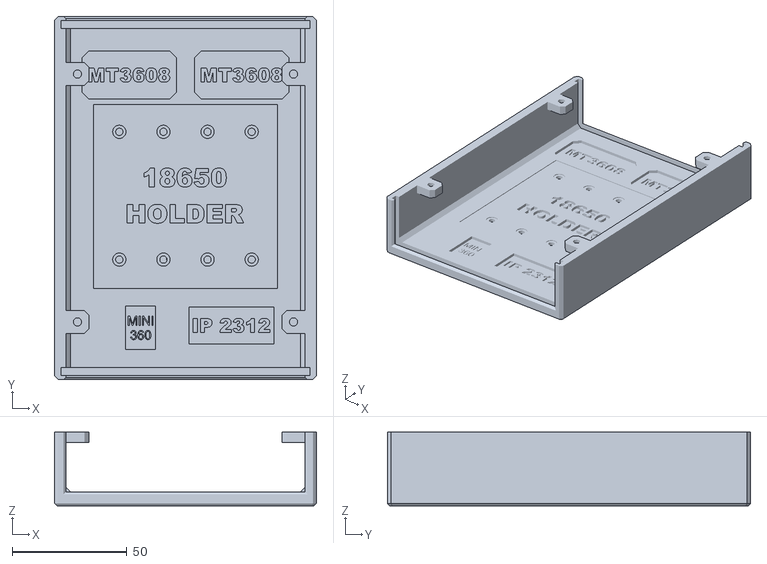
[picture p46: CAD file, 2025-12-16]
3D Models/V1.1 (Latest)/STLs/Case.stl
114.0 x 158.0 x 32.0

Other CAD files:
3D Models/V1.0/STLs/Front_Panel.stl
3D Models/V1.1 (Latest)/STLs/Back_Panel.stl

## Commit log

2025-12-16 Add circuit image
2025-12-16 Add 3D Files
    [Back_Panel.stl, Case.stl, Cover.stl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]
